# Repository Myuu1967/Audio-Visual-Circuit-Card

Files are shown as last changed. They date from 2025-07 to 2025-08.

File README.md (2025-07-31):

# Audio-Visual-Circuit-Card
- ArduinoIDE_File/doremifa     　　Xiao ESP32C3用のスケッチです。内容を変更することで、名刺基板の動きを変更できます。<br>
- KiCAD8_Files    　　回路図と基板のデータが入っています（KiCAD８で書かれています）<br>
    * XiaoESP32C3Doremifa.backups    　　(上のフォルダーの中身です)　回路図等のバックアップです（必要ないかも）<br>
    * footprint/Library.pretty    　　基板の図面用のフットプリントです。登録することで図面にフットプリントが表示されるようになると思います<br>
    * symnbol    　　回路図のシンボルです。上のフォルダーの中身同様、登録することで回路図にシンボルが描かれるようになります（お手数かけます）<br>
    * XiaoESP32C3Doremifa.kicad_*    　　KiCAD用のファイルです。KiCAD８にて書きました。（上のバージョンのKiCADでも閲覧はできます）
    * XiaoESP32C3Doremifa.pdf    　　回路図のPDFファイルです。KiCADがインストールされていなくても閲覧で得きるかと思います。

- README.md    　　このファイルです。
- partslist.csv    　　この名刺基板用のパーツリストです

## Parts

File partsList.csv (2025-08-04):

Reference | Value | Datasheet | Footprint | Qty | DNP | 秋月電子 販売コード | 備考
C1,C2 | 10u | ~ | Capacitor_SMD:C_0603_1608Metric_Pad1.08x0.95mm_HandSolder | 2 |  | 113161
C3,C4 | 0.1u | ~ | Capacitor_SMD:C_0603_1608Metric_Pad1.08x0.95mm_HandSolder | 2 |  | 113374
C5 | 220u | ~ | Capacitor_SMD:CP_Elec_10x10 | 1 |  | 104577 | 5個セット
C6 | 47u | ~ | Capacitor_SMD:C_1210_3225Metric_Pad1.33x2.70mm_HandSolder | 1 |  | 116078
D1 | 1N4007 | ~ | Diode_THT:D_5W_P10.16mm_Horizontal | 1 |  | 100934 | 耐圧が十分なら代用品可（１Vのツェナーダイオードでもいいです。取り付ける向きは逆になります）
D2 | LED | ~ | LED_SMD:LED_0603_1608Metric_Pad1.05x0.95mm_HandSolder | 1 |  | 108274
D3,D4,D5,D6,D7 | WS2812B | https://cdn-shop.adafruit.com/datasheets/WS2812B.pdf | LED_SMD:LED_WS2812B_PLCC4_5.0x5.0mm_P3.2mm | 5 |  | 107915 | 2個入り
J1 | B2B-XH-A_LF__SN_ | http://www.jst-mfg.com/product/pdf/eng/eXH.pdf | digikey-footprints:PinHeader_1x2_P2.5mm_Drill1.1mm | 1 |  | 112247 | コネクタを使用する場合、メス側も用意する必要があります
J2 | Conn_01x03_Socket | ~ | Connector_PinSocket_2.54mm:PinSocket_1x03_P2.54mm_Vertical | 1 |  | 105779 | 分割して使ってください
LS1 | Speaker | ~ | Connector_PinSocket_2.54mm:PinSocket_1x02_P2.54mm_Vertical | 1 |  | 112587 | （一例です）
R1 | 10 | ~ | Resistor_SMD:R_0603_1608Metric_Pad0.98x0.95mm_HandSolder | 1 |  | 113832 | 千石電商にて10個入りあり
R2 | 4.7K | ~ | Resistor_SMD:R_0603_1608Metric_Pad0.98x0.95mm_HandSolder | 1 |  | 130353
R3,R4 | 10K | ~ | Resistor_SMD:R_0603_1608Metric_Pad0.98x0.95mm_HandSolder | 2 |  | 130355
R5 | 470 | ~ | Resistor_SMD:R_0603_1608Metric_Pad0.98x0.95mm_HandSolder | 1 |  | 130349
RV1 | 10K |  |  | 1 |  | 114905 | ピン幅と配置が同じで抵抗値が同じなら代用品可
S1,S2,S3,S4,S5 | 1825910-6 | https://www.te.com/commerce/DocumentDelivery/DDEController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 | digikey-footprints:Switch_Tactile_THT_6x6mm | 5 |  | 103647 | 色違いあります
SW1 | SW_SPDT | ~ | Library:sw_slide | 1 |  | 115707
SW2 | SW_DIP_x02 | ~ | Button_Switch_THT:SW_DIP_SPSTx02_Slide_9.78x7.26mm_W7.62mm_P2.54mm | 1 |  | 103141
U1 | LM386 | http://www.ti.com/lit/ds/symlink/lm386.pdf | Package_SO:SO-8_5.3x6.2mm_P1.27mm | 1 |  | 114549
U2 | ~ |  | Library:xiaoEsp32C3 | 1 |  | 117454
 | ※ご要望によっては部品の販売を行うかもしれないです（不手際申し訳ありません）

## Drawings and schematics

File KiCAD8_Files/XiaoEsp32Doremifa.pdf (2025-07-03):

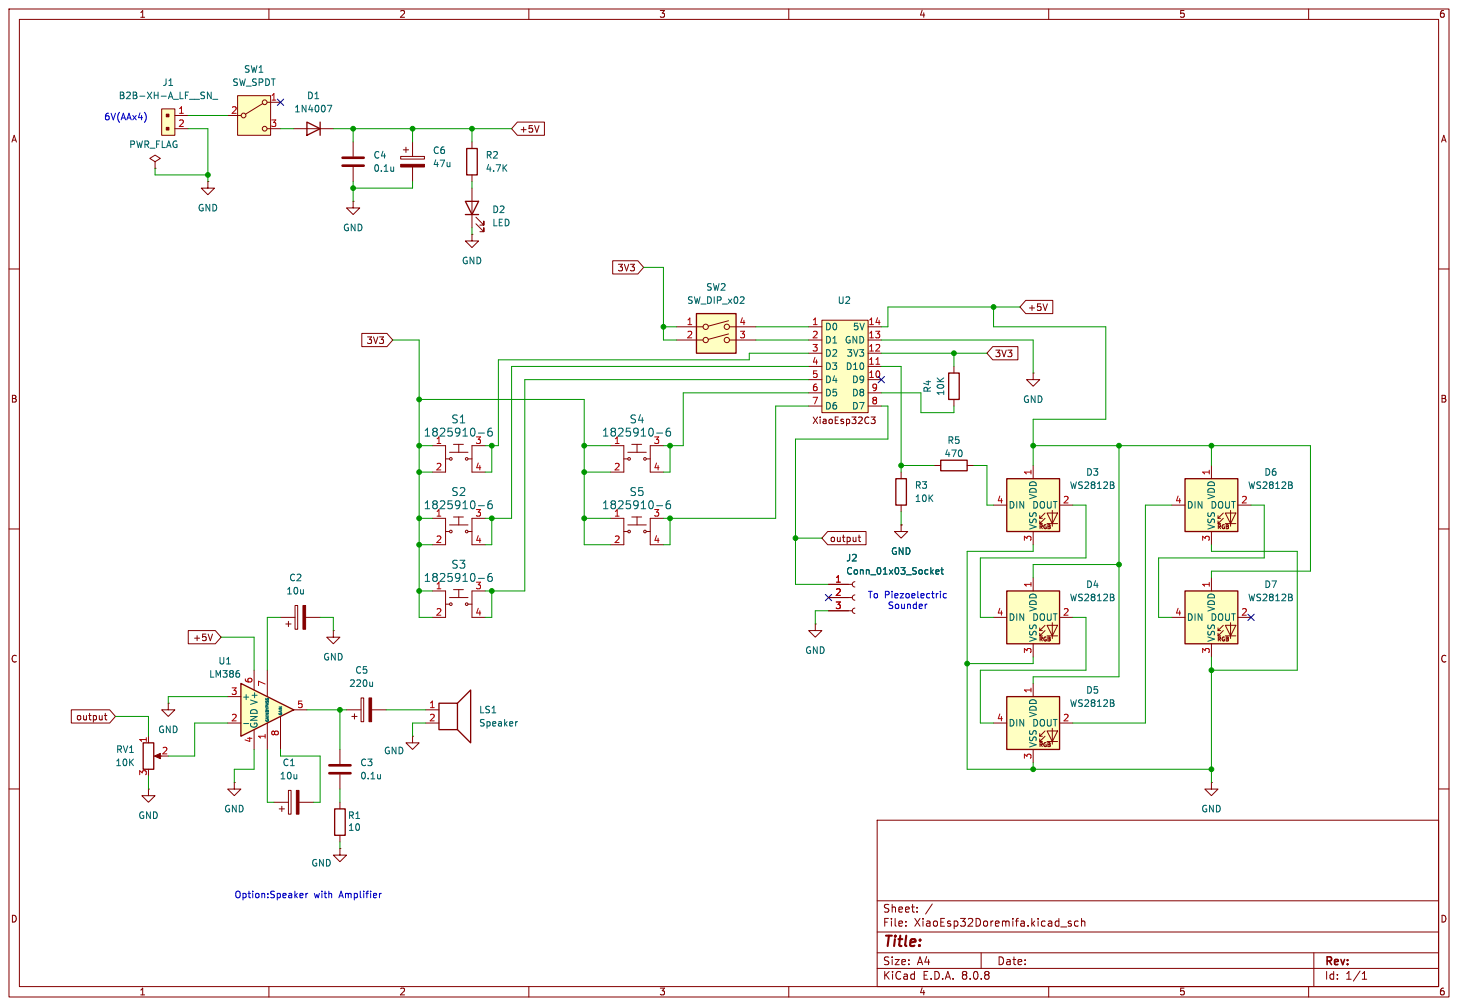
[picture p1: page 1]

Id: 1/1 Title: File: XiaoEsp32Doremifa.kicad_sch Sheet: /

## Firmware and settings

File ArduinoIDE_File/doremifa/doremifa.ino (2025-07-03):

#include <Adafruit_NeoPixel.h>  // WS2812B用のヘッダファイル

#define LED_PIN     D10      // WS2812Bに接続しているピン
#define NUM_LEDS    5        // 全体のLED数（5個つながっている）
#define BRIGHTNESS  10       // 明るさ（0〜255）

// ドレミファの周波数
const int tones[] = {261, 294, 329, 349, 392};    // C4, D4, E4, F4, G4　音階の周波数
const int buttons[] = {D2, D3, D4, D5, D6};       // D2～D5　タクトスイッチにつながるピン
const int speakerPin = D7;                        // D7　圧電サウンダー（スピーカー用のアンプ）につながるピン
int currentTone = -1; // 現在鳴らしている音のインデックス（-1 = 無音）

const int sw1 = D0;    // DIPスイッチ右側
const int sw2 = D1;    // DIPスイッチ左側

int rainbowCNT = 0;    // mode0 時にWS2812Bを虹色に光らせるためのカウンタ

int AmbulanceCNT = 0;   // mode1で救急車のサイレンを鳴らすときのカウンタ
int   rider[5][8] = {{100, 30, 20, 0, 0, 0, 20, 30},
                    {30, 100, 30, 20, 0, 20, 30, 100},
                    {20, 30, 100, 30, 20, 30, 100, 30},
                    {0, 20, 30, 100, 30, 100, 30, 20}, 
                    {0, 0, 20, 30, 100, 30, 20, 0} } ;      // 救急車の赤色灯を光らせるための配列
int   riderCNT = 0;     // 救急車の赤色灯を光らせるときのカウンタ

int   PoliceCNT = 0;    // パトカーのサイレンを鳴らすときのカウンタ
int   patternCNT = 0;   // パトカーのパトライトを光らせるためのカウンタ
int   bombCNT = 0;      // 爆弾を鳴らすときのカウンタ
int   popSoundCNT = 0;  // mode1のとき、popSoundを鳴らすときのカウンタ
int   popSoundCNT2 = 0; // mode1のとき、popSoundでWS2812Bを光らせるときのカウンタ
int   chordCNT = 0;     // mode2のとき、和音（？）を奏でるためのカウンタ
int   chords[5][3] = {{261, 329, 392}, // C, E, G
                      {294, 370, 440}, // D, F, A
                      {329, 415, 493}, // E, G, B
                      {349, 440, 523}, // F, A, C
                      {392, 493, 587} } ; // G, B, D（和音のコード）

int  displayCNT = 0;    // mode2のとき、WS2812Bを光らせるときのカウンタ

Adafruit_NeoPixel strip(NUM_LEDS, LED_PIN, NEO_GRB + NEO_KHZ800);     // WS2812Bのインスタンスを取得

// 色変換関数
uint32_t Wheel(byte WheelPos) {
  WheelPos = 255 - WheelPos;
  if (WheelPos < 85) {
    return strip.Color(255 - WheelPos * 3, 0, WheelPos * 3);
  }
  if (WheelPos < 170) {
    WheelPos -= 85;
    return strip.Color(0, WheelPos * 3, 255 - WheelPos * 3);
  }
  WheelPos -= 170;
  return strip.Color(WheelPos * 3, 255 - WheelPos * 3, 0);
}

// レインボーアニメーション
void rainbowCycleStep() {

  rainbowCNT = (rainbowCNT + 2) % 255;
    for (int i = 0; i < 5; i++) {
      strip.setPixelColor(i, Wheel((i * 85 / 5 + rainbowCNT) & 255));
    }
    strip.show();
}

// ホワイト
void whiteCycle(uint8_t wait) {
  for (int i = 0; i < 5; i++) {
    strip.setPixelColor(i, strip.Color(70, 70, 70)); // 白 (R,G,B)
  }
  strip.show();
  delay(wait);
  for (int i = 0; i < 5; i++) {
    strip.setPixelColor(i, strip.Color(0, 0, 0)); // 白 (R,G,B)
  }
  strip.show();
  delay(wait);
}

// ダミーの関数
void colorSingle(int index) {
  ws2812Clear(); // 一度すべて消してから
  if (index >= 0 && index < NUM_LEDS) {
    strip.setPixelColor(index, strip.Color(255, 0, 0)); // 赤色
    strip.show();
  }
}

// WS2812Bをクリアする関数
void ws2812Clear(void ){
  for (int i = 0; i < 16; i++) {
    strip.setPixelColor(i, strip.Color(0, 0, 0)); // 赤 (R,G,B)
  }
  strip.show(); // 変更を反映}
}

// マシンガンの音を鳴らす関数
void playMachineGunSound(int pin) {
  tone(pin, 150);
  delay(30);
  noTone(pin);
  delay(12);
}

// 救急車のサイレンを鳴らす関数
void playAmbulanceSiren(int pin) {
  AmbulanceCNT = (AmbulanceCNT + 1) % 10;

  if(AmbulanceCNT < 5){
    tone(pin, 660);      // 低い音（ポー）
  }else if(AmbulanceCNT < 10){
    tone(pin, 880);      // 高い音（ピッ）
  }
  delay(100);
  
}

// 救急車の赤色灯を光らせる関数
void nightRider(){
  for(int i=0; i < 5; i++){
    strip.setPixelColor(i, strip.Color(rider[i][riderCNT], 0, 0)); // 赤 (R,G,B)
  }
  riderCNT = (riderCNT + 1) % 8;
  strip.show(); // 変更を反映}
}

// パトカーのサイレンを鳴らす関数
void playPoliceSiren(int pin) {
  int hertz;

  PoliceCNT = (PoliceCNT + 1) % 20;
  if(PoliceCNT < 12){
    hertz = 870 + PoliceCNT * 8;
    tone(pin, hertz);   // 高音「ファン」
    delay(80);
  }else{
    for(int i = 0; i < 6 ; i++){
      hertz = 790 - i * 12;
      tone(pin, hertz);   // 高音「ファン」
      delay(20);
    }
  }
}

// パトカーのパトライトを光らせる関数（補助）
uint32_t policeRGB(int pattern) {
  if (pattern == 0) {
    return strip.Color(150, 0, 0);
  }
  if (pattern == 1) {
    return strip.Color(0, 0, 150);
  }
}

// パトカーのパトライトを光らせる関数（メイン）
void policePattern(){
  for(int i=0; i < 5; i++){
    strip.setPixelColor(i, policeRGB(patternCNT)); // 赤 (R,G,B)
    patternCNT = (patternCNT + 1) % 2;
  }
  strip.show(); // 変更を反映}
}

// ポップなサウンドを鳴らす関数
void playCutePopSound(int pin) {
  int melody[] = { 523, 659, 784 };  // C5, E5, G5（上昇する三和音）
  int duration = 100;  // 各音の長さ（ms）

  popSoundCNT = (popSoundCNT + 1) % 3;
  tone(pin, melody[popSoundCNT]);
  delay(duration);
}

// ポップなサウンドのときにWS2812Bを光らせる関数
void popSoundRGB(){
  popSoundCNT2 = (popSoundCNT2 + 15) % 255;
  for(int i=0; i < 5; i++){
    strip.setPixelColor(i, Wheel((popSoundCNT2) & 255));
  }
  strip.show(); // 変更を反映

}

// 爆弾の音と光を発生させる関数
void playBombEffect(int pin) {
  // 落下音（低音→高音）
  strip.setBrightness(100);
  bombCNT = 0;
  for(int i = 0; i < 50; i++){
    int f = i * 18 + 300;
    tone(pin, f);
    for(int j=0; j < 5; j++){
      strip.setPixelColor(j, Wheel(((byte)(255 - i * 213 / 50)) & 255)); // 赤 (R,G,B)
    }
    strip.show(); // 変更を反映
    delay(15);
  }

  noTone(pin);
  delay(100);
  for(int i=0; i < 5; i++){
    strip.setPixelColor(i, Wheel(42));
  }
  strip.show(); // 変更を反映

  // 爆発音：ランダムな短いtone
  for(int i=0; i < 50; i++){
    tone(pin, random(100, 250));
    delay(25);
    bombCNT = bombCNT++;

    int bright = (i % 4) * 40;
    strip.setBrightness(bright);
    for(int j=0; j < 5; j++){
    strip.setPixelColor(j, Wheel(42));
    }
    strip.show(); // 変更を反映

  }
}

// 和音（コード）を奏でる関数
void playChord(int newTone) {
  int pin = D7;
  tone(pin, chords[newTone][chordCNT]);
  delay(100);  // 少し重なりつつ発音

}

// mode2のとき、WS2812Bを光らせる関数
void displayWS2812B(int newTone){
  displayCNT = (displayCNT + 1) % 2;
  if(newTone == 0){
    if(displayCNT < 1){
      for (int i = 0; i < 5; i++) {
        strip.setPixelColor(i, strip.Color(200, 0, 0)); // 赤系フェード
        strip.show();
      }
    }else if(displayCNT < 2){
      ws2812Clear();
    }
  }else if(newTone == 1){
    for (int i = 0; i < 5; i++) {
    strip.setPixelColor(i, Wheel(random(255))); // ランダム色
      strip.show();
    }
  }else if(newTone == 2){
    if(displayCNT < 1){
      for (int i = 0; i < 5; i++) {
        strip.setPixelColor(i, strip.Color(150, 150, 0));
        strip.show();
      }
    }else if(displayCNT < 2){
      ws2812Clear();
    }
  }else if(newTone == 3){
    if(displayCNT < 1){
      for (int i = 0; i < 5; i++) {
          strip.setPixelColor(i, strip.Color(0, 0, 200));
      }
      strip.show();
    }else if(displayCNT < 2){
      ws2812Clear();
    }
  }else if(newTone == 4){
    if(displayCNT < 1){
      for (int i = 0; i < 5; i++) {
        strip.setPixelColor(i, strip.Color(0, 200, 0)); // 緑系点滅
      }
      strip.show();
    }else if(displayCNT < 2){
      ws2812Clear();
    }
  }
}


// ドアのベルを鳴らす関数
void playDoorBellWithLED(int pin) {
  // ピン
  tone(pin, 1046);
  for (int i = 0; i < 5; i++) {
    strip.setPixelColor(i, strip.Color(255, 255, 255)); // 白く光る
  }
  strip.show();
  delay(150);
  noTone(pin);
  ws2812Clear();
  delay(100);

  // ポーン
  tone(pin, 784);
  for (int i = 0; i < 5; i++) {
    strip.setPixelColor(i, strip.Color(50, 50, 255)); // 青っぽい
  }
  strip.show();
  delay(300);
  noTone(pin);
  ws2812Clear();
}

// 蒸気音を奏でる関数（失敗作）
void playSteamLocomotive(int pin) {
  // シュッシュッ（短いパルス音を繰り返し）
  for (int i = 0; i < 6; i++) {
    tone(pin, 200 + random(50)); // ノイズ風に少しばらす
    strip.setPixelColor(i % 5, strip.Color(100, 100, 100)); // 灰色に
    strip.show();
    delay(80);
    noTone(pin);
    ws2812Clear();
    delay(100);
  }

  delay(300); // 間を取る

  // ポーッ（汽笛）
  tone(pin, 440); // A4あたり
  for (int i = 0; i < 5; i++) {
    strip.setPixelColor(i, strip.Color(0, 0, 255)); // 青
  }
  strip.show();
  delay(1000); // 長く鳴らす
  noTone(pin);
  ws2812Clear();
}

// 蒸気音っぽいエフェクト音（？）
void playSteamNoise(int pin) {
  for (int i = 0; i < 6; i++) {
    for (int j = 0; j < 30; j++) {
      int f = random(300, 800);  // ランダム周波数でノイズ風
      tone(pin, f);
      delay(3);  // ごく短く鳴らす
    }
    noTone(pin);
    delay(100); // シュッの間隔
  }
}


// 初期設定
void setup() {
  strip.begin();            // 初期化
  strip.setBrightness(BRIGHTNESS); 

  for (int i = 0; i < 5; i++) {
    pinMode(buttons[i], INPUT_PULLDOWN); // 内部プルダウン設定（ESP32-C3で可能）
  }
  pinMode(speakerPin, OUTPUT);

  pinMode(sw1, INPUT_PULLDOWN); // 内部プルダウン設定（ESP32-C3で可能）
  pinMode(sw2, INPUT_PULLDOWN); // 内部プルダウン設定（ESP32-C3で可能）

  for (int i = 0; i < 5; i++) {
    strip.setPixelColor(i, strip.Color(0, 0, 0)); // 赤 (R,G,B)
  }
  strip.show(); // 変更を反映}


}

void loop() {
  int newTone = -1;
  int mode = 0;

  if (digitalRead(sw1) == LOW) {
    if (digitalRead(sw2) == LOW) {
      mode = 0;
    } else {
      mode = 1;
    }
  } else {
    if (digitalRead(sw2) == LOW) {
      mode = 2;
    } else {
      mode = 3;
    }
  }

  // どのボタンが押されているかチェック
  newTone = -1;
  for (int i = 0; i < 5; i++) {
    if (digitalRead(buttons[i]) == HIGH) {
      newTone = i;
      break;
    }
  }

// mode0~3の場合分け それぞれにおいて
// どのタクトスイッチが押されたかで応答が変わる
  if (mode == 0) {
    if (newTone != -1) {
      if (newTone != currentTone) {
        tone(speakerPin, tones[newTone]);
        currentTone = newTone;
      }
      rainbowCycleStep();  // ここで毎ループ色を進める
    } else {
      noTone(speakerPin);
      ws2812Clear();
      currentTone = -1;
    }
  }else if(mode == 1){
    currentTone = newTone;
    if (newTone == 0) {
      playMachineGunSound(speakerPin);
      whiteCycle(10);
    }else if (newTone == 1) {
      nightRider();
      playAmbulanceSiren(speakerPin); // D3を押すと救急車の音
    }else if (newTone == 2) {
      policePattern();
      playPoliceSiren(speakerPin);  // D4を押すとファンファン
    }else if (newTone == 3) {
      // popSoundRGB();
      // playCutePopSound(speakerPin);

      // playDoorBellWithLED(speakerPin);

      // playSteamLocomotive(speakerPin);

      playSteamNoise(speakerPin);
    }else if (newTone == 4) {
      playBombEffect(speakerPin);
    }
    noTone(speakerPin);
    ws2812Clear();
  }else if(mode == 2){
    if (newTone != -1) {
      currentTone = newTone;
      chordCNT = (chordCNT + 1) % 3;
      displayWS2812B(newTone);
      playChord(newTone);
    } else {
      noTone(speakerPin);
      ws2812Clear();
      currentTone = -1;
    }
  }else if(mode == 3){
    // 今後の拡張モード用
    ws2812Clear();
    noTone(speakerPin);
  }


  delay(10);

}

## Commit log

2025-07-21 Update README.md
    お待ちください
2025-07-31 Update README.md
    マークダウンにて書きました
2025-08-04 modify partsList.csv concerning RV1
    [partsList.csv]
2025-08-04 add new comment to RV1 in the partsList.csv
    [partsList.csv]
